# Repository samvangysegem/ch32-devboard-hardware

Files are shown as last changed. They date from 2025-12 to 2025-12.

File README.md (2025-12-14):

# CH32 Development Board

This repository contains hardware design files and documentation for a development board based on the CH32V30x series of microcontrollers. The board features USB-FS and UART communication interfaces, as well as input current monitoring. It is intended as a test and development platform for projects using the CH32V30x family.

Documentation is available in the [docs](./docs) folder, including:
- [Component datasheets and specifications](./docs/01_specs/)
- [Design calculations](./docs/02_calcs/)

For compatible firmware, see the related firmware repository
➡️ [ch32-devboard-firmware](https://github.com/samvangysegem/ch32-devboard-firmware)

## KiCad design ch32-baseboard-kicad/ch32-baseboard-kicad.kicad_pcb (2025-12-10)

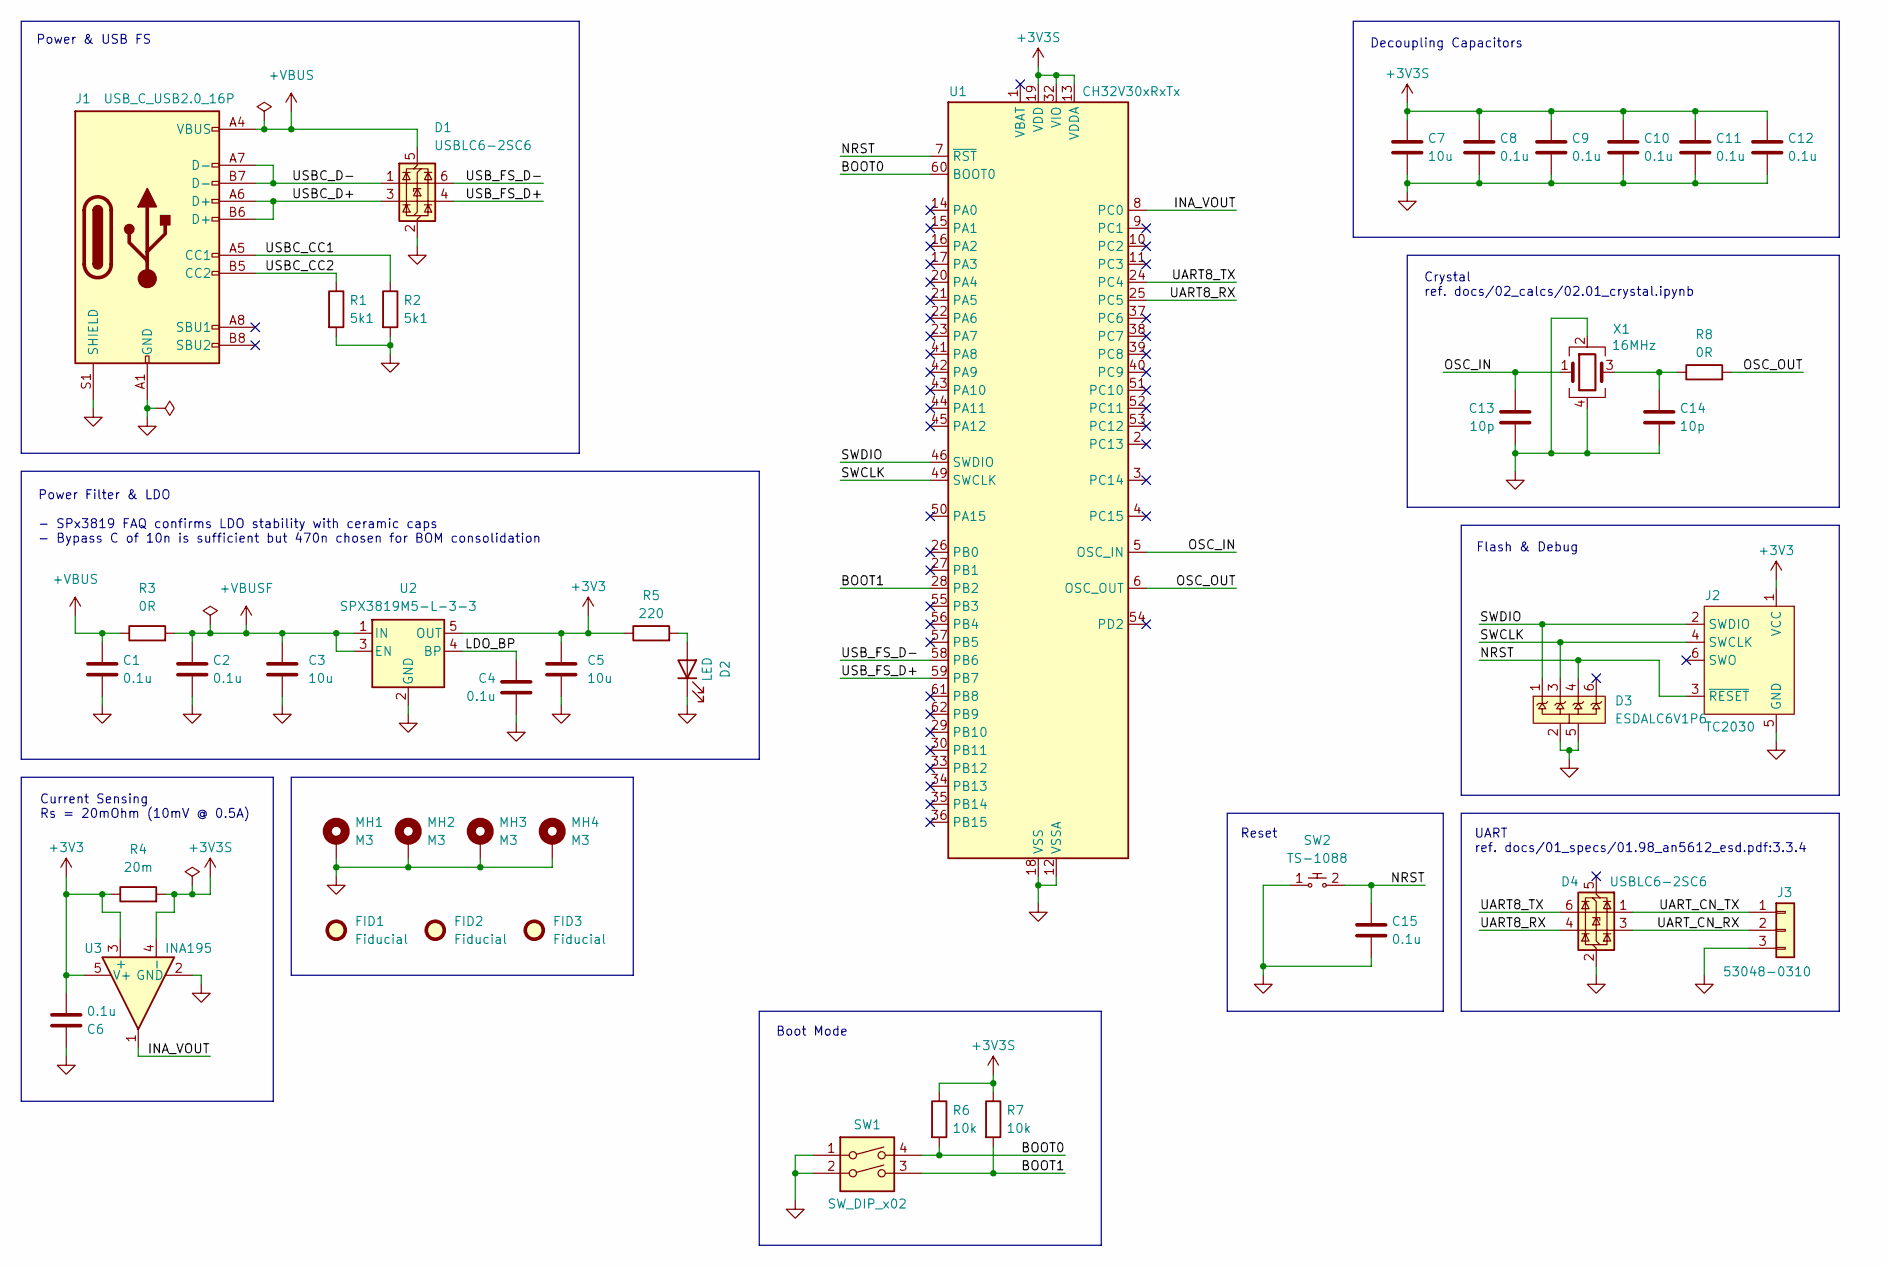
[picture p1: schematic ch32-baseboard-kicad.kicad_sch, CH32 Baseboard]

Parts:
C1, C2, C4, C6, C8, C9, C10, C11, C12, C15: 0.1u; C_0402_1005Metric; Manufacturer Part Number CL05B104KO5NNNC
C3, C5, C7: 10u; C_0805_2012Metric; Manufacturer Part Number CL21A106KAYNNNE
C13, C14: 10p; C_0402_1005Metric; Manufacturer Part Number CL05C100JB5NNNC
D1, D4: USBLC6-2SC6; SOT-23-6
D2: LED; LED_0603_1608Metric; Manufacturer Part Number KT-0603W
D3: ESDALC6V1P6; SOT-666IP-STM; Manufacturer Part Number ESDALC6V1P6
FID1, FID2, FID3: Fiducial; Fiducial_1mm_Mask2mm
J1: USB_C_USB2.0_16P; USB_C_Receptacle_GCT_USB4105-xx-A_16P_TopMnt_Horizontal; Manufacturer Part Number TYPE-C 16PIN 2MD(073); JLCPCB Part Number C2765186
J2: TC2030; Tag-Connect_TC2030-IDC-FP_2x03_P1.27mm_Vertical
J3: 53048-0310; Molex_PicoBlade_53048-0310_1x03_P1.25mm_Horizontal; Manufacturer Part Number 530480310
MH1, MH2, MH3, MH4: M3; MountingHole_3.2mm_M3_Pad_Via
R1, R2: 5k1; R_0402_1005Metric; Manufacturer Part Number 0402WGF5101TCE
R3: 0R; R_0805_2012Metric_Pad1.20x1.40mm_HandSolder; Manufacturer Part Number 0805W8F0000T5E
R4: 20m; R_1206_3216Metric; Manufacturer Part Number LR1206-21R020F4
R5: 220; R_0603_1608Metric; Manufacturer Part Number 0603WAF2200T5E
R6, R7: 10k; R_0603_1608Metric; Manufacturer Part Number 0603WAF1002T5E
R8: 0R; R_0402_1005Metric; Manufacturer Part Number 0402WGF0000TCE
SW1: SW_DIP_x02; SW_DIP_SPSTx02_Slide_6.7x6.64mm_W8.61mm_P2.54mm_LowProfile; Manufacturer Part Number SMXS-02K-TP
SW2: TS-1088; SW_SPST_TS-1088-xR020; Manufacturer Part Number TS-1088-AR02016
U1: CH32V30xRxTx; LQFP-64_10x10mm_P0.5mm; JLCPCB C2988083
U2: SPX3819M5-L-3-3; SOT-23-5; Manufacturer Part Number SPX3819M5-L-3-3/TR
U3: INA195; SOT-23-5
X1: 16MHz; Crystal_SMD_3225-4Pin_3.2x2.5mm; Manufacturer Part Number X322516MLB4SI

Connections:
+3V3: C5.1, C6.2, J2.1 (VCC), R4.1, R5.1, U2.5 (OUT), U3.3 (+), U3.5 (V+)
+3V3S: C7.1, C8.1, C9.1, C10.1, C11.1, C12.1, R4.2, R6.1, R7.1, U1.13 (VDDA), U1.19 (VDD), U1.32 (VIO), U1.48 (VDD), U1.64 (VIO), U3.4 (-)
+VBUS: C1.1, D1.5 (VBUS), J1.A4 (VBUS), J1.A9 (VBUS), J1.B4 (VBUS), J1.B9 (VBUS), R3.1
+VBUSF: C2.1, C3.1, R3.2, U2.1 (IN), U2.3 (EN)
/BOOT0: R6.2, SW1.4, U1.60 (BOOT0)
/BOOT1: R7.2, SW1.3, U1.28 (PB2)
/INA_VOUT: U1.8 (PC0), U3.1
/LDO_BP: C4.1, U2.4 (BP)
/NRST: C15.1, D3.4, J2.3 (~RESET), SW2.2, U1.7 (~RST)
/OSC_IN: C13.1, U1.5 (OSC_IN), X1.1
/OSC_OUT: R8.2, U1.6 (OSC_OUT)
/SWCLK: D3.3, J2.4 (SWCLK), U1.49 (SWCLK)
/SWDIO: D3.1, J2.2 (SWDIO), U1.46 (SWDIO)
/UART8_RX: D4.4 (I/O2), U1.25 (PC5)
/UART8_TX: D4.6 (I/O1), U1.24 (PC4)
/UART_CN_RX: D4.3 (I/O2), J3.2
/UART_CN_TX: D4.1 (I/O1), J3.1
/USBC_CC1: J1.A5 (CC1), R2.1
/USBC_CC2: J1.B5 (CC2), R1.1
/USBC_D+: D1.3 (I/O2), J1.A6 (D+), J1.B6 (D+)
/USBC_D-: D1.1 (I/O1), J1.A7 (D-), J1.B7 (D-)
/USB_FS_D+: D1.4 (I/O2), U1.59 (PB7)
/USB_FS_D-: D1.6 (I/O1), U1.58 (PB6)
GND: C1.2, C2.2, C3.2, C4.2, C5.2, C6.1, C7.2, C8.2, C9.2, C10.2, C11.2, C12.2, C13.2, C14.2, C15.2, D1.2 (GND), D2.1 (K), D3.2, D3.5, D4.2 (GND), J1.A1 (GND), J1.A12 (GND), J1.B1 (GND), J1.B12 (GND), J1.S1 (SHIELD), J2.5 (GND), J3.3, MH1.1, MH2.1, MH3.1, MH4.1, R1.2, R2.2, SW1.1, SW1.2, SW2.1, U1.12 (VSSA), U1.18 (VSS), U1.31 (VSS), U1.47 (VSS), U1.63 (VSS), U2.2 (GND), U3.2 (GND), X1.2, X1.4
unnamed: C14.1, R8.1, X1.3
unnamed: D2.2 (A), R5.2

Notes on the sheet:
UART ref. docs/01_specs/01.98_an5612_esd.pdf:3.3.4
Current Sensing Rs = 20mOhm (10mV @ 0.5A)
Reset
Crystal ref. docs/02_calcs/02.01_crystal.ipynb
Power & USB FS
Decoupling Capacitors
Boot Mode
Flash & Debug
Power Filter & LDO - SPx3819 FAQ confirms LDO stability with ceramic caps - Bypass C of 10n is sufficient but 470n chosen for BOM consolidation

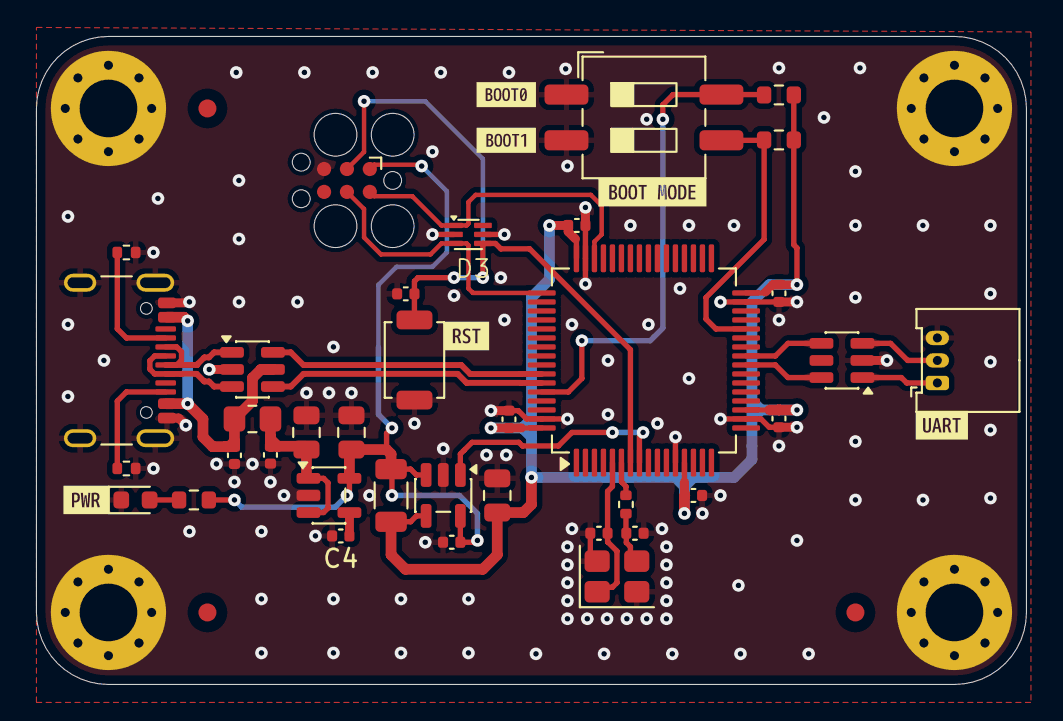
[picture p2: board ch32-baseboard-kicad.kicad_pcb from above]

Board: 4 copper layers, 55.0 x 36.0 mm, 49 parts (0 on the bottom side), 26 nets.

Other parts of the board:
kibuzzard-692C82B7: G***; kibuzzard-692C82B7
kibuzzard-692C82FA: G***; kibuzzard-692C82FA
kibuzzard-692C811E: G***; kibuzzard-692C811E
kibuzzard-692C8041: G***; kibuzzard-692C8041
kibuzzard-6935C0F9: G***; kibuzzard-6935C0F9
kibuzzard-6935C105: G***; kibuzzard-6935C105

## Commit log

2025-12-10 feat: ch32 baseboard v1.1
    [ch32-baseboard-kicad.kicad_pcb, ch32-baseboard-kicad.kicad_sch]
2025-12-14 chore: cleanup
    [ch32-baseboard-kicad-B_Cu.gbr, ch32-baseboard-kicad-B_Mask.gbr, ch32-baseboard-kicad-Edge_Cuts.gbr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]
